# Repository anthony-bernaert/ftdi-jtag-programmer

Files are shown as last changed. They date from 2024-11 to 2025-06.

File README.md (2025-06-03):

# FTDI-based JTAG Programmer for FPGAs
This JTAG programmer board is based on an FTDI chip and supports Lattice, AMD (Xilinx), Intel (Altera) FPGAs, and probably more. It allows those devices to be programmed and debugged over USB through their regular toolchains.

The board also provides a separate UART port for general-purpose serial communication between a PC application and any other board.

If you work with a lot of different FPGAs, this solution can be used as a universal, cost-effective replacement for most of your vendor-specific JTAG cables.

## Features
- Based on the FT2232H chip
- USB-C connector
- On-board resettable fuse to protect your host's USB port
- 1 JTAG port
  - Programs and debugs Lattice, AMD/Xilinx, Altera/Intel, and probably also other FPGAs through their respective toolchains
  - Standard 2 mm Xilinx 2x7 header connector
  - Also has a 6-pin 2.54 mm header for use with jumper wires
  - Voltage reference input pin configures the I/O voltage (2.5-5V)
  - An LED indicates presence of an external VREF voltage
- 1 UART port
  - Generic serial communication through virtual COM port
  - 6-pin 2.54 mm header, pinout compatible with FTDI's TTL-232R cables
  - Configurable 5V output or voltage reference input (2.5-5V) (*)
  - An LED indicates presence of an external VREF voltage
- Buffered I/O pins with surge protection
  - Outputs are current-limited
  - Inputs are 5V tolerant
- For Xilinx/AMD and Lattice, only the standard FTDI software drivers are needed
 
(*) These are mounting variations, so to be decided during PCB assembly.

## Build overview




This board was designed using KiCad 7.0.2.

Navigate to the releases section to obtain the latest production files and schematic. The BOM contains references to LCSC parts, so that you can easily order PCB assemblies at e.g. JLCPCB.

Files for 3D printing an optional enclosure are also provided. The enclosure is recommended to prevent accidental shorts during use.



It consists of a top and bottom part, which slide in horizontally; no screws or glue are necessary. For resilience and visibility of the LEDs, it is recommended to print it in a translucent PETG material.

## How to use
### First-time configuration
Install FTDI's VCP/D2XX drivers for your operating system [from their website](https://ftdichip.com/drivers/).

Also install [FT_PROG](https://ftdichip.com/utilities/#ft_prog). This utility will be used to initialize the EEPROM of the board with the correct settings.

Now you can choose to either initialize the EEPROM using FT_PROG or directly flash the device using an existing EEPROM dump.

>[!TIP]
>The most versatile solution is to flash the EEPROM with the Digilent SMT1 dump. The programmer then works simultaneously for Vivado, ISE, Diamond and Quartus (details in the [Xilinx ISE section](#xilinx-ise)).
>
>However, for the very first startup of your board, please try to write the following settings using the FT_PROG utility. This way, you can make sure that your hardware and drivers are working properly.

When FT_PROG is installed, connect the board to your PC. At this point, the green PWREN LED should be on: this means the PC has enumerated the device. If this is not the case, see the [Troubleshooting Guide](TROUBLESHOOTING.md).

In FT_PROG, scan and parse the connected devices. Configure your board as follows:
- Port A
  - Set the hardware mode to "245 FIFO"
  - Set the driver to D2XX Direct
- Port B
  - Set the hardware mode to "RS232 UART"
  - Set the driver to Virtual COM Port
 



Finally, program this configuration into the EEPROM. Depending on the vendor of the FPGA you want to program, a few additional steps might be needed. These are described below.

### Lattice
To use the programmer with Lattice devices, just open the programming software such as Diamond Programmer and select the 'HW-USBN-2B (FTDI)' option as the cable type.

Diamond programmer can use any FTDI device configured in D2XX mode. No additional configuration is needed.



>[!NOTE]
>This programmer is known to work with Diamond Programmer software - other tools, such as Radiant Programmer, have not been tested yet.

### AMD/Xilinx Vivado
For AMD/Xilinx tools, the software looks for a Xilinx signature in the FTDI device EEPROM. Once this is done, the programmer appears as any other official programming cable in Vivado Hardware Manager. To add the signature, you have two options: either write a recognized EEPROM dump to the device (recommended), or use AMD's `program_ftdi` utility.

The recommended way is to use the Digilent SMT1 dump; refer to the [Xilinx ISE section](#xilinx-ise) on how to do this.

If you really want to do it AMD's way: recent Vivado versions (starting from 2022) contain the `program_ftdi` tool that configures FTDI chips as AMD/Xilinx JTAG programmers. Running this utility (once) will make the programmer work with Vivado. You can execute it from the TCL console, e.g. in the Hardware Manager of Vivado. Run a command similar to this one:
```
program_ftdi -write -ftdi FT2232H -serial 0ABC01 -vendor "my vendor co" -board "my board" -desc "my product desc"
```
Note that the 'serial' parameter must match the serial number generated by FT_PROG. After programming, the programmer should show up in the Hardware Manager of Vivado.



>[!WARNING]
>Unfortunately, it seems that the `program_ftdi` is broken in Vivado 2024.1. If you see it complaining about missing DLLs while trying to program, try using an older version of Vivado, e.g. 2023.2, which is known to work.

### Xilinx ISE
To use this programmer with Xilinx' older ISE toolchain, you'll need to flash the EEPROM to mimick a legacy Digilent SMT1 device. You will find the required EEPROM dump on [dragonlock2's ftdi_dumps repository](https://github.com/dragonlock2/ftdi_dumps?tab=readme-ov-file). Afterwards, the device appears as a Digilent SMT1 device in the cable setup window.

Note that this dump has the advantage that you can make the programmer work simultaneously for Vivado, ISE, Diamond and Quartus, turning your programmer in an (at least) 4-in-1 solution!

>[!TIP]
>Writing the EEPROM configuration can be done using the (Linux) utility `ftdi_eeprom` or my own [FTDI EEPROM cloning tool](https://github.com/anthony-bernaert/ftdi-cloner).

Once the EEPROM is programmed, the cable appears as a Digilent USB JTAG cable:



### Altera/Intel
For Quartus software to work with FT2232HL devices, one option is to add a library file to your Quartus installation directory. You'll find a ready-made DLL (if you're on Windows) [here](https://github.com/anthony-bernaert/jtag-mpsse-blaster). This is a fork of an open-source solution that adds FTDI MPSSE support to Quartus Programmer/Signal Tap. Linux is also supported, though I did not test this.

After installing the .dll/.so file, the JTAG programmer board should show up in the available hardware list of Quartus and your FPGA is ready to be programmed:



If you don't like modifying your Quartus installation manually, an alternative solution is to configure the USB device as an 'Arrow USB Blaster'. You will find the required EEPROM dump on [dragonlock2's ftdi_dumps repository](https://github.com/dragonlock2/ftdi_dumps?tab=readme-ov-file).

>[!TIP]
>Writing the EEPROM configuration can be done using the (Linux) utility `ftdi_eeprom` or my own [FTDI EEPROM cloning tool](https://github.com/anthony-bernaert/ftdi-cloner).

In this case, you also need to install the [Arrow USB Blaster driver](https://shop.trenz-electronic.de/en/Download/?path=Trenz_Electronic/Software/Drivers/Arrow_USB_Programmer). After this, your FTDI programmer should appear in the hardware list of Quartus Programmer and your FPGA is ready to be programmed.



## Troubleshooting
If you experience problems while using this board, check out the [Troubleshooting Guide](TROUBLESHOOTING.md).

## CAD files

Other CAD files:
Enclosure/Enclosure-Rev2.f3d

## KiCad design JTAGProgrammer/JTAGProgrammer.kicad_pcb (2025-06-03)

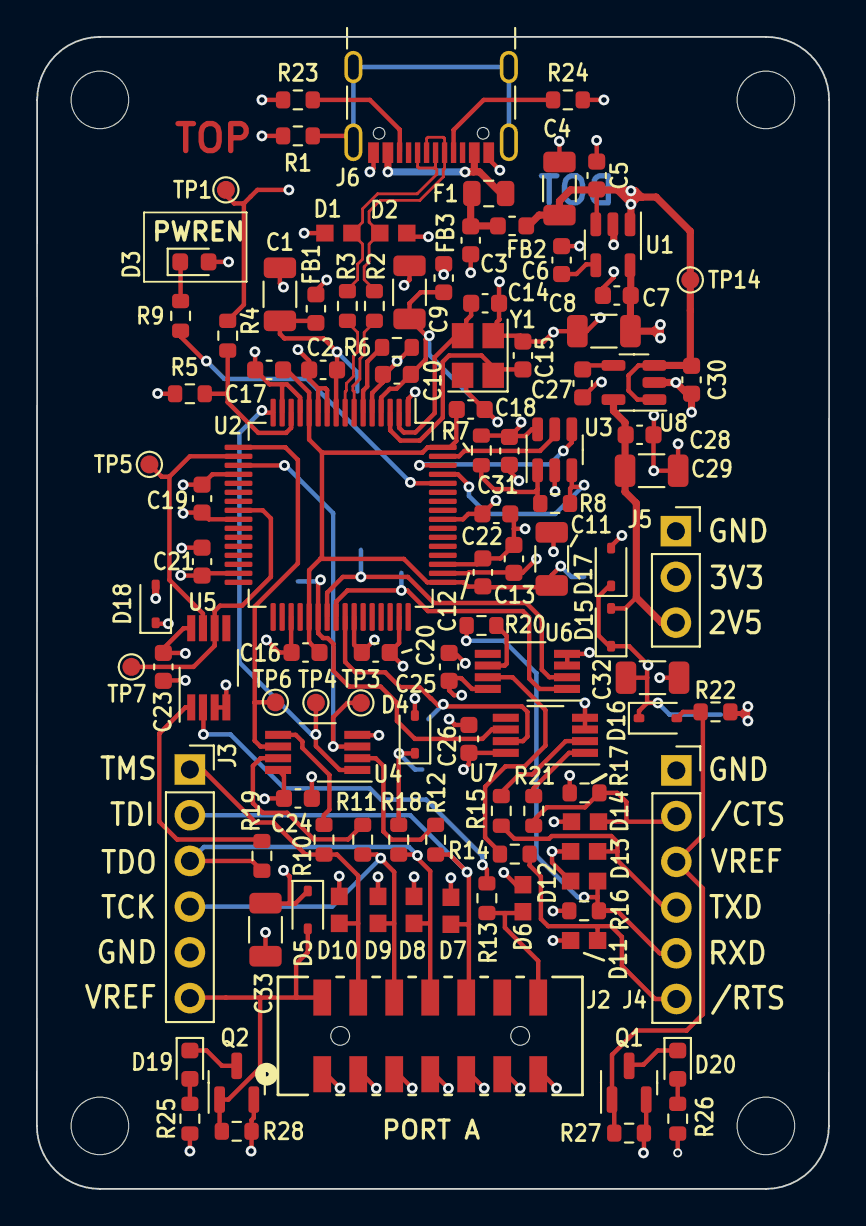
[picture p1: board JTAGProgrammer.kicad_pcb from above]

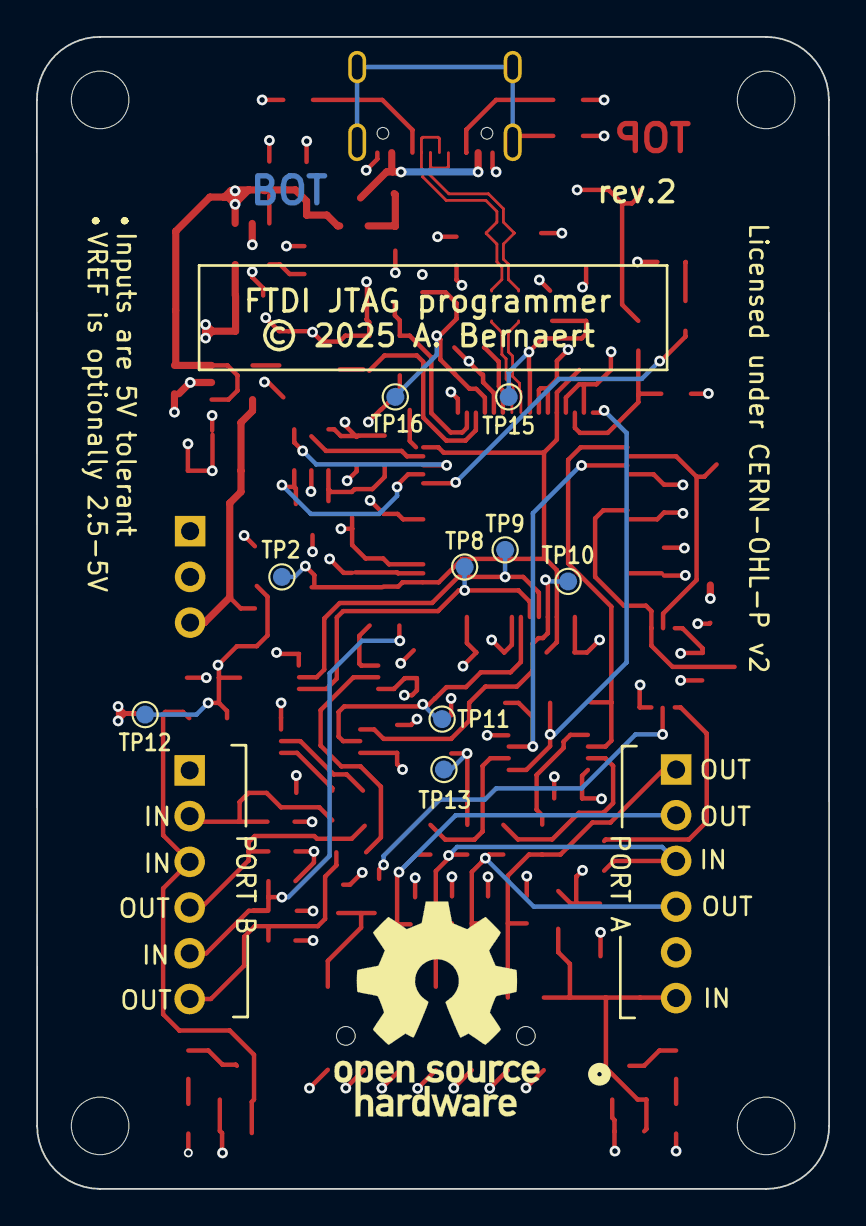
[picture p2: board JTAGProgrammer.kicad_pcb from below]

Board: 4 copper layers, 44.0 x 64.0 mm, 121 parts (9 on the bottom side), 63 nets.

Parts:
C1, C4, C8, C9, C11, C29, C32, C33: 4.7u; C_1206_3216Metric
C2, C5, C7, C10, C12, C13, C16, C17, C18, C19, C20, C21, C22, C23, C24, C25, C26, C28, C30, C31: 100n; C_0603_1608Metric
C3, C6, C27: 10n; C_0603_1608Metric
C14, C15: 10p; C_0603_1608Metric
D1, D2, D6, D7, D8, D9, D10, D11, D12, D13, D14: PGB1010603MR; DIOC1608X36N
D3, D19, D20: LED; LED_0603_1608Metric
D4, D5, D15, D16, D17, D18: CUS520,H3F; D_SOD-323
F1: 0805L075SLYR; Fuse_0805_2012Metric
FB1, FB2, FB3: BLM18AG601SN1D; L_0603_1608Metric
H1, H2, H3, H4: MountingHole; MountingHole_3.2mm_M3
J2: 878325623; CONN_87832-5623_MOL
J3, J4: Conn_01x06; PinSocket_1x06_P2.54mm_Vertical
J5: Conn_01x03; PinSocket_1x03_P2.54mm_Vertical
J6: USB_C_Receptacle_USB2.0; USB_C_Receptacle_GCT_USB4105-xx-A_16P_TopMnt_Horizontal
Q1, Q2: BSS123; SOT-23
R1, R22: 0R; R_0603_1608Metric
R2, R3: 10R; R_0603_1608Metric
R4: 15K; R_0603_1608Metric
R5, R7, R16, R17, R18, R27, R28: 10K; R_0603_1608Metric
R6: 12K; R_0603_1608Metric
R8: 2.2K; R_0603_1608Metric
R9, R25, R26: 100R; R_0603_1608Metric
R10, R11, R12, R13, R14, R15, R19, R20, R21: 150R; R_0603_1608Metric
R23, R24: 5K1; R_0603_1608Metric
TP1, TP2, TP3, TP4, TP5, TP6, TP7, TP8, TP9, TP10, TP11, TP12, TP13, TP14, TP15, TP16: TestPoint; TestPoint_Pad_D1.0mm
U1: LP2985-3.3; SOT-23-5
U2: FT2232HL; LQFP-64_10x10mm_P0.5mm
U3: 93LC56B; SOT-23-6
U4, U5, U6, U7: 74LVC3G17; VSSOP-8_3.0x3.0mm_P0.65mm
U8: LP2985-2.5; SOT-23-5
Y1: RH100-12.000-10-3030-TR; Crystal_SMD_3225-4Pin_3.2x2.5mm

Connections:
+1V8: C11.1, C12.1, C16.1, C17.1, C18.1, TP2.1, U2.12 (VCORE), U2.37 (VCORE), U2.49 (VREGOUT), U2.64 (VCORE)
+2V5: C28.1, C29.1, D4.2 (A), D15.2 (A), J5.3, U8.5 (VOUT)
+3V3: C7.1, C8.1, C13.1, C19.1, C20.1, C21.1, C22.1, C31.1, D3.2 (A), D17.2 (A), D18.2 (A), FB1.1, FB3.1, J5.2, R7.2, R25.1, R26.1, U1.5 (VOUT), U2.20 (VCCIO), U2.31 (VCCIO), U2.42 (VCCIO), U2.50 (VREGIN), U2.56 (VCCIO), U3.6 (VCC)
/FTDI/FTDI_D+: R3.2, U2.8 (DP)
/FTDI/FTDI_D-: R2.2, U2.7 (DM)
/FTDI/JTAG_SRST: TP7.1, U2.24 (ADBUS7), U5.6
/FTDI/JTAG_TCK: TP4.1, U2.16 (ADBUS0), U4.1
/FTDI/JTAG_TDI: TP6.1, U2.17 (ADBUS1), U4.6
/FTDI/JTAG_TDO: TP5.1, U2.18 (ADBUS2), U5.7
/FTDI/JTAG_TMS: TP3.1, U2.19 (ADBUS3), U4.3
/FTDI/UART_CTS: TP11.1, U2.41 (BDBUS3), U7.7
/FTDI/UART_RTS: TP8.1, U2.40 (BDBUS2), U6.1
/FTDI/UART_RXD: TP9.1, U2.39 (BDBUS1), U6.2
/FTDI/UART_TXD: TP10.1, U2.38 (BDBUS0), U7.6
/FTDI/VPHY: C9.1, C10.1, FB3.2, TP16.1, U2.4 (VPHY)
/FTDI/VPLL: C1.1, C2.1, FB1.2, TP15.1, U2.9 (VPLL)
/JTAG/SRST_BUF: D6.1, J2.14, R13.2
/JTAG/TCK_BUF: D9.1, J2.6, J3.4, R11.2
/JTAG/TDI_BUF: D7.1, J2.10, J3.2, R12.2
/JTAG/TDO_CONN: D8.1, J2.8, J3.3, R18.1, R19.2
/JTAG/TMS_BUF: D10.1, J2.4, J3.1, R10.2
/JTAG/VIO_JTAG: C23.1, C24.1, C33.1, D4.1 (K), D5.1 (K), D18.1 (K), R18.2, TP13.1, U4.8 (VCC), U5.8 (VCC)
/JTAG/VREF: D5.2 (A), J2.2, J3.6, Q2.1 (G), R28.2
/Power/VBUS: F1.1, J6.A4 (VBUS), J6.A9 (VBUS), J6.B4 (VBUS), J6.B9 (VBUS)
/UART/CTS_CONN: D14.1, J4.2, R17.1, R21.2
/UART/RTS_BUF: D11.1, J4.6, R14.2
/UART/RXD_CONN: D12.1, J4.5, R16.1, R20.2
/UART/TXD_BUF: D13.1, J4.4, R15.2
/UART/VIO_UART: C25.1, C26.1, C32.1, D15.1 (K), D16.1 (K), D17.1 (K), R16.2, R17.2, TP12.1, U6.8 (VCC), U7.8 (VCC)
/UART/VREF_CONN: D16.2 (A), J4.3, Q1.1 (G), R22.2, R27.2
/USB_D+: D1.1, J6.A6 (D+), J6.B6 (D+), R3.1
/USB_D-: D2.1, J6.A7 (D-), J6.B7 (D-), R2.1
/USB_SHIELD: J6.S1 (SHIELD), R1.1
/VBUS_FILT: C4.1, C5.1, C30.1, FB2.2, R4.1, R22.1, TP1.1, TP14.1, U1.1 (VIN), U1.3 (ON/~OFF), U8.1 (VIN), U8.3 (ON/~OFF)
GND: C1.2, C2.2, C3.2, C4.2, C5.2, C6.2, C7.2, C8.2, C9.2, C10.2, C11.2, C12.2, C13.2, C14.2, C15.2, C16.2, C17.2, C18.2, C19.2, C20.2, C21.2, C22.2, C23.2, C24.2, C25.2, C26.2, C27.2, C28.2, C29.2, C30.2, C31.2, C32.2, C33.2, D1.2, D2.2, D6.2, D7.2, D8.2, D9.2, D10.2, D11.2, D12.2, D13.2, D14.2, J2.1, J2.3, J2.5, J2.7, J2.9, J2.11, J2.13, J3.5, J4.1, J5.1, J6.A1 (GND), J6.A12 (GND), J6.B1 (GND), J6.B12 (GND), Q1.2 (S), Q2.2 (S), R1.2, R5.1, R6.1, R23.2, R24.2, R27.1, R28.1, U1.2 (GND), U2.1 (GND), U2.5 (GND), U2.10 (AGND), U2.11 (GND), U2.13 (TEST), U2.15 (GND), U2.25 (GND), U2.35 (GND), U2.47 (GND), U2.51 (GND), U3.2 (GND), U4.4 (GND), U5.3, U5.4 (GND), U6.3, U6.4 (GND), U7.3, U7.4 (GND), U8.2 (GND), Y1.2, Y1.4
unnamed: C3.1, F1.2, FB2.1
unnamed: D3.1 (K), R9.2
unnamed: D19.2 (A), R25.2
unnamed: D19.1 (K), Q2.3 (D)
unnamed: D20.2 (A), R26.2
unnamed: D20.1 (K), Q1.3 (D)
unnamed: J6.A5 (CC1), R24.1
unnamed: J6.B5 (CC2), R23.1
unnamed: R10.1, U4.5
unnamed: R11.1, U4.7
unnamed: R12.1, U4.2
unnamed: R13.1, U5.2
unnamed: R14.1, U6.7
unnamed: R15.1, U7.2
unnamed: R19.1, U5.1
unnamed: R20.1, U6.6
unnamed: R21.1, U7.1
unnamed: C6.1, U1.4 (BP)
unnamed: U2.62 (EECLK), U3.4 (CLK)
unnamed: U2.63 (EECS), U3.5 (CS)
unnamed: R8.2, U2.61 (EEDATA), U3.3 (DI)
unnamed: C14.1, U2.2 (OSCI), Y1.3
unnamed: C15.1, U2.3 (OSCO), Y1.1
unnamed: R6.2, U2.6 (REF)
unnamed: R9.1, U2.60 (~PWREN)
unnamed: R4.2, R5.2, U2.14 (~RESET)
unnamed: R7.1, R8.1, U3.1 (DO)
unnamed: C27.1, U8.4 (BP)

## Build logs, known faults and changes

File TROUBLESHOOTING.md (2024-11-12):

# Troubleshooting Guide
## Hardware issues
In case your board doesn't start up right away, or does not enumerate over USB, be sure to check following things:
### Solder joints
  - Inspect all pins of FTDI chip, are they properly soldered without shorts in-between? The pitch is rather small, so be sure to double-check this first.
  - Inspect the USB connector, especially the ground pin: this directly connects to a ground plane which has a higher thermal mass and it takes longer to properly solder this pin.
  - Inspect the crystal: if soldered by hand, this component might be a bit tricky to solder properly, as the pads are (mostly) underneath the device. If you have it available, reseat it using a heat gun.
### Check the power
Check there is 5V (on TP14), 3.3V (on J5, pin 2), VPHY 3.3V (TP16), VPLL 3.3V (TP15), 2.5V (on J5, pin 3) and 1.8V (on TP2).
  - It's good to check the current draw of the board: it should be well under 100 mA. If it's higher, something is definitely wrong!
  - If there is no 5V, the issue might be the USB connector soldering, the input filter (ferrite bead) or the USB cable. Before trying (to fry) another USB port, it may be wise to apply 5V from a lab supply instead and verify current draw first.
  - If there is no 3.3V or 2.5V: check regulators U1 and U8.
  - If there is no VPHY or VPLL, check the ferrite filter between 3.3V and the VPHY/VPLL rail.
  - If there is no 1.8V: check the FTDI chip itself, does it get hot, does it have shorts on its pins?
### Crystal behavior
If you have an oscilloscope, measure the OSCI/OSCO signals.
  - Do you see the crystal starting up? If yes, is it a stable wave (a centered sine-like wave on OSCI, and a more square-like wave on OSCO)? Does it have the right frequency (12 MHz)? It might stop running abruptly (after like 10 ms) if there was an enumeration failure, so be sure to also measure when plugging in the device.
  - If it is unstable, try tuning the load capacitors (check the datasheet of the crystal). FTDI suggests to use 27 pF capacitors as a default, but recommends verifying the crystal manufacturer's specification.

### EEPROM corruption
Make sure you are not using an EEPROM with corrupt FTDI configuration data. This can happen after writing the device EEPROM with an invalid dump (specifically when it has a correct checksum and invalid configuration data).

Unfortunately, this puts the device in a 'bricked' state and the only solution is to replace the EEPROM chip. To verify that the EEPROM is at fault, desolder the 93LC56B chip and plug in the device. Without an EEPROM, the FTDI chip boots with default settings (which of course you cannot change until you put in a new EEPROM chip).

## Software issues
If the board starts up correctly (PWREN LED on) and is recognized by your operating system, driver issues might still throw a spanner in the works.
### FT_PROG doesn't see any devices
  - An issue I encountered was that FT_PROG couldn't load the FTD2XX.dll driver, but did not show any error message at first glance. However, you can see the issue when you go to the command line. 
If you see errors like
```Failed to load FTD2XX.DLL. Are the FTDI drivers installed?```
 it might indicate that the drivers are not correctly installed.

![image](https://github.com/user-attachments/assets/3cb0e7bc-4c6b-4b76-bfcc-057fb22ccd2d)

  - Comparing the loaded driver files on a PC where everything works fine with one where FT_PROG does not work, the difference was the the SysWOW64\ftd2xx.dll. This line was absent on the failing PC:
![image](https://github.com/user-attachments/assets/85e6d831-0830-48f8-b945-0272bcba0667)
  - While not ideal, the only working solution I found until now is to manually delete the drivers in the above list, and run the FTDI CDM driver setup again.
  - Other people have resolved similar issues by using another USB cable. Be sure to use a quality cable that is not only intended for charging!
### Vivado cannot run `program_ftdi`, it either segfaults, complains about missing DLLs or cannot find the command
  - Only Vivado 2022 and newer have the utility included
  - It seems things are broken in Vivado 2024; try using a lower version such as Vivado 2023.2
  - Alternatively, use the Linux tool `ftdi_eeprom` or my own FTDI EEPROM dumper tool to configure an FTDI device with a Xilinx 'fingerprint'.

### USB driver conflicts
If you used ESP32 development boards in the past, you might have used a tool like Zadig to replace USB drivers for FT2232H devices. If you have this installed, make sure that the correct (FTDI) driver is not automatically replaced for the JTAG programmer board, as can be seen here:

![thumbnail_image](https://github.com/user-attachments/assets/4f74fd7b-d4f5-47e7-9d5e-4f84b8ec60e5)

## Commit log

2024-11-03 Check-in of revision 1
    [FTDI.kicad_sch, JTAG.kicad_sch, JTAGProgrammer.kicad_pcb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]
2024-11-06 Add USB driver conflict to troubleshooting guide
2024-11-13 Add LCSC part numbers
    [FTDI.kicad_sch, JTAG.kicad_sch, JTAGProgrammer.kicad_pcb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]
2024-11-13 Fix wrong comment in schematic on UART VREF/5V mounting options
    [FTDI.kicad_sch, JTAG.kicad_sch, JTAGProgrammer.kicad_sch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]
2025-06-03 Rev.2: change to USB Type-C, add VBUS fuse, VREF LED indicators
    [FTDI.kicad_sch, JTAG.kicad_sch, JTAGProgrammer.kicad_pcb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]
2025-06-03 Add enclosure design file
    [Enclosure-Rev2.f3d]

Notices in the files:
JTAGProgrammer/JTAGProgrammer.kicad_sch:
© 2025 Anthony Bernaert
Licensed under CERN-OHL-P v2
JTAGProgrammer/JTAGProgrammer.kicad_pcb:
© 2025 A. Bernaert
